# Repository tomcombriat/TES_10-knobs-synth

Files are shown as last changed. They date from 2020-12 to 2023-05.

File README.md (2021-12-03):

# TES - 10 knobs synth
T. Combriat 

10 knobs synths are simple synthesizers based on [Mozzi](https://github.com/sensorium/Mozzi) using STM32 blue pill with 10 knobs. Different versions are available:

  - 10knobs_mono_24bits_MCP4822 is a mono synth built around the MCP4822 dual DAC, with theoritical 24 bits resolution (in practice, around 14/16 bits get outside the noise, but that is already quite a lot). It can easily be turned into a stereo synth with 12bits on each channel.
  - 10knobs_mono_16bits_PT8211 is a mono synth built around the PT8211 dual DAC, with theoritical 16 bits resolution. This one can easily be upgraded to a stereo version: only one channel of the PT8211 is used here.

The aim of this serie is to provide a quite fixed hardware which can be used for different synthesis methods.

***

### Hardware
These synthesizers have: 
* MIDI input and thru
* 10 knobs for controlling parameters (thus the name), note that one is hardwired for logarithmic volume control
* 6.35mm analog (DAC) audio output (mono/stereo)
* standalone power from ~~3~~ 4 AA batteries. This ensures cleaner sound thanks to very stable power lines. This has been changed from 3 to 4 in order to get some room over the signal level for the op-amps.

PCBs for the chip are single faced and can be easily made if one is able to make 220 microns wide tracks. The masks are provided in the hardware folders for each version.

***

### Programming
These synths can be programmed like any other STM32 pills using USB to serial converter. Native USB will usually not work. You will  also need a rather new version of the Arduino IDE with Mozzi installed and modify Mozzi in accordance with the beginning of the sketch or use the [TES forked version of Mozzi](https://github.com/tomcombriat/Mozzi/tree/TES-stable).

As a general matter, the programs tries to use the most of the chip, so it usually needs to be compiled with -O2 or -O3 with the maximum overclock. As the chip is not confined, the OC does not pose any problem.

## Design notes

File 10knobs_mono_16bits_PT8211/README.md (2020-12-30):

## 10 knobs mono

Actual working version of 10 knobs synth. Features an STM32 BluePill, with DAC used defined output (STANDARD_PLUS 24bits of Mozzi @ 32k)

  - hardware folder contains the kicad project and the masks for an homemade PCB (in svg format).
  - softwares folder contains the different Arduino sketches that can be uploaded on this synth.

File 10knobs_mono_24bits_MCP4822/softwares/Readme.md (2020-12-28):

  - Hardware_check: a test sketch for the PCB integrity
  - MCP4922_mono_24bits_SPI2_trimming: a sketch to trim the synth with an oscilloscope (should give a straight line)
  - XORAND_sax_mk2: a remake of the XORAND_sax synth (from the 8k serie): a synth to be used with an EWI. This is a good base if you want to start your own synth.

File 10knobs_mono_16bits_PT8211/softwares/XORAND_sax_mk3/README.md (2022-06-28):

## TES - XORAND sax mk3
T. Combriat

A version of [XORAND synth](https://github.com/tomcombriat/8_knobs_synth/tree/master/XORAND_poly) to be used with an EWI or the [TESaxophone](https://t-e-s.frama.site/en/tesaxophone).
Differences include:
* Polyphony: 16
* Chords on separate MIDI channel
* Breath controlled volume and filter

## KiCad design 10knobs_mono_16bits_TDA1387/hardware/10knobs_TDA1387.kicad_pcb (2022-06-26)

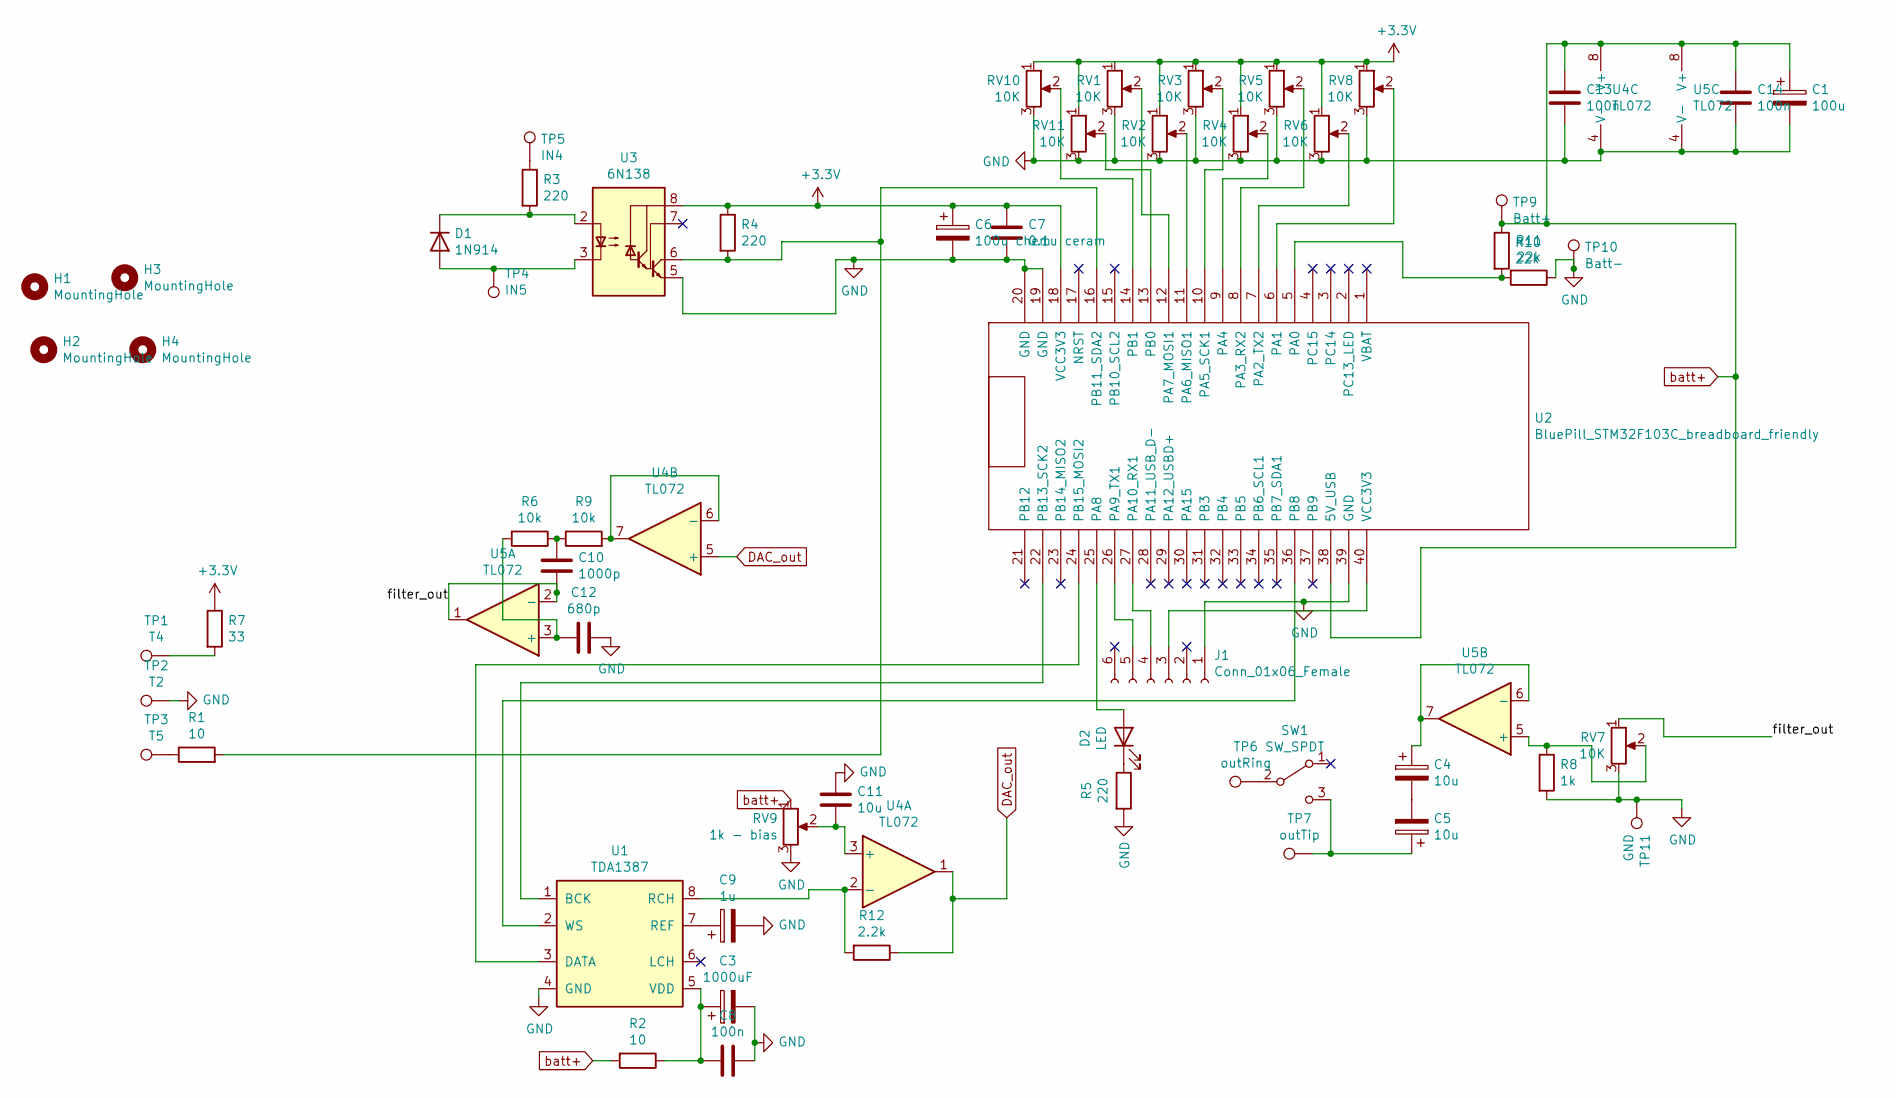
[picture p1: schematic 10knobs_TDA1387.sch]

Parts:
C1: 100u; CP_Radial_D5.0mm_P2.50mm
C3: 1000uF; CP_Radial_D7.5mm_P2.50mm
C4, C5, C11: 10u; CP_Radial_D5.0mm_P2.50mm
C6: 100u chem; CP_Radial_D5.0mm_P2.50mm
C7: 0.1u ceram; C_Disc_D3.0mm_W2.0mm_P2.50mm
C8: 100n; C_Disc_D3.0mm_W2.0mm_P2.50mm
C9: 1u; CP_Radial_D5.0mm_P2.50mm
C10: 1000p; C_Disc_D5.0mm_W2.5mm_P2.50mm
C12: 680p; C_Disc_D5.0mm_W2.5mm_P2.50mm
C13, C14: 100n; C_Disc_D5.0mm_W2.5mm_P2.50mm
D1: 1N914; D_DO-35_SOD27_P7.62mm_Horizontal
D2: LED; LED_D3.0mm
H1, H2, H3, H4: MountingHole; MountingHole_3.2mm_M3_ISO7380_Pad
J1: Conn_01x06_Female; PinHeader_1x06_P2.54mm_Vertical
R1, R2: 10; R_Axial_DIN0207_L6.3mm_D2.5mm_P7.62mm_Horizontal
R3, R4, R5: 220; R_Axial_DIN0207_L6.3mm_D2.5mm_P7.62mm_Horizontal
R6, R9: 10k; R_Axial_DIN0207_L6.3mm_D2.5mm_P7.62mm_Horizontal
R7: 33; R_Axial_DIN0207_L6.3mm_D2.5mm_P7.62mm_Horizontal
R8: 1k; R_Axial_DIN0207_L6.3mm_D2.5mm_P7.62mm_Horizontal
R10, R11: 22k; R_Axial_DIN0207_L6.3mm_D2.5mm_P7.62mm_Horizontal
R12: 2.2k; R_Axial_DIN0207_L6.3mm_D2.5mm_P7.62mm_Horizontal
RV1, RV2, RV3, RV4, RV5, RV6, RV7, RV8, RV10, RV11: 10K; Potentiometer_Alps_RK09K_Single_Vertical
RV9: 1k - bias; Potentiometer_Bourns_3296W_Vertical
SW1: SW_SPDT; PinSocket_1x03_P2.54mm_Vertical
TP1: T4; TestPoint_THTPad_2.5x2.5mm_Drill1.2mm
TP2: T2; TestPoint_THTPad_2.5x2.5mm_Drill1.2mm
TP3: T5; TestPoint_THTPad_2.5x2.5mm_Drill1.2mm
TP4: IN5; TestPoint_THTPad_2.5x2.5mm_Drill1.2mm
TP5: IN4; TestPoint_THTPad_2.5x2.5mm_Drill1.2mm
TP6: outRing; TestPoint_THTPad_2.5x2.5mm_Drill1.2mm
TP7: outTip; TestPoint_THTPad_2.5x2.5mm_Drill1.2mm
TP9: Batt+; TestPoint_THTPad_2.5x2.5mm_Drill1.2mm
TP10: Batt-; TestPoint_THTPad_2.5x2.5mm_Drill1.2mm
TP11: GND; TestPoint_THTPad_2.5x2.5mm_Drill1.2mm
U1: TDA1387; SO-8_3.9x4.9mm_P1.27mm
U2: BluePill_STM32F103C_breadboard_friendly
U3: 6N138; DIP-8_W7.62mm
U4, U5: TL072; DIP-8_W7.62mm_Socket_LongPads

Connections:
+3V3: C6.1, C7.1, R4.1, R7.1, RV1.1, RV2.1, RV3.1, RV4.1, RV5.1, RV6.1, RV8.1, RV10.1, RV11.1, U2.18 (VCC3V3), U3.8 (VCC)
/filter_out: C10.2, RV7.1, U5.1, U5.2 (-)
DAC_out: R12.1, U4.1, U4.5 (+)
GND: C1.2, C3.2, C6.2, C7.2, C8.1, C9.2, C11.1, C12.1, C13.2, C14.2, J1.1, R5.2, R8.2, R11.1, RV1.3, RV2.3, RV3.3, RV4.3, RV5.3, RV6.3, RV7.3, RV8.3, RV9.3, RV10.3, RV11.3, TP2.1, TP10.1, TP11.1, U1.4 (GND), U2.19 (GND), U2.20 (GND), U2.39 (GND), U3.5 (GND), U4.4 (V-), U5.4 (V-)
unnamed: C3.1, C8.2, R2.1, U1.5 (VDD)
unnamed: C4.1, U5.6 (-), U5.7
unnamed: C4.2, C5.2
unnamed: C5.1, SW1.3 (C), TP7.1
unnamed: C9.1, U1.7 (REF)
unnamed: C10.1, R6.1, R9.1
unnamed: C11.2, RV9.2, U4.3 (+)
unnamed: C12.2, R6.2, U5.3 (+)
unnamed: D1.1 (K), R3.2, U3.2 (C1)
unnamed: D1.2 (A), TP4.1, U3.3 (C2)
unnamed: D2.1 (K), R5.1
unnamed: D2.2 (A), U2.25 (PA8)
unnamed: J1.3, U2.40 (VCC3V3)
unnamed: J1.4, U2.27 (PA10_RX1)
unnamed: J1.5, U2.26 (PA9_TX1)
unnamed: R1.1, TP3.1
unnamed: R1.2, R4.2, U2.16 (PB11_SDA2), U3.6 (VO2)
unnamed: R3.1, TP5.1
unnamed: R7.2, TP1.1
unnamed: R8.1, RV7.2, U5.5 (+)
unnamed: R9.2, U4.6 (-), U4.7
unnamed: R10.2, R11.2, U2.5 (PA0)
unnamed: R12.2, U1.8 (RCH), U4.2 (-)
unnamed: RV1.2, U2.12 (PA7_MOSI1)
unnamed: RV2.2, U2.11 (PA6_MISO1)
unnamed: RV3.2, U2.10 (PA5_SCK1)
unnamed: RV4.2, U2.9 (PA4)
unnamed: RV5.2, U2.8 (PA3_RX2)
unnamed: RV6.2, U2.7 (PA2_TX2)
unnamed: RV8.2, U2.6 (PA1)
unnamed: RV10.2, U2.14 (PB1)
unnamed: RV11.2, U2.13 (PB0)
unnamed: SW1.2 (B), TP6.1
unnamed: U1.1 (BCK), U2.22 (PB13_SCK2)
unnamed: U1.2 (WS), U2.36 (PB8)
unnamed: U1.3 (DATA), U2.24 (PB15_MOSI2)
batt+: C1.1, C13.1, C14.1, R2.2, R10.1, RV9.1, TP9.1, U2.38 (5V_USB), U4.8 (V+), U5.8 (V+)

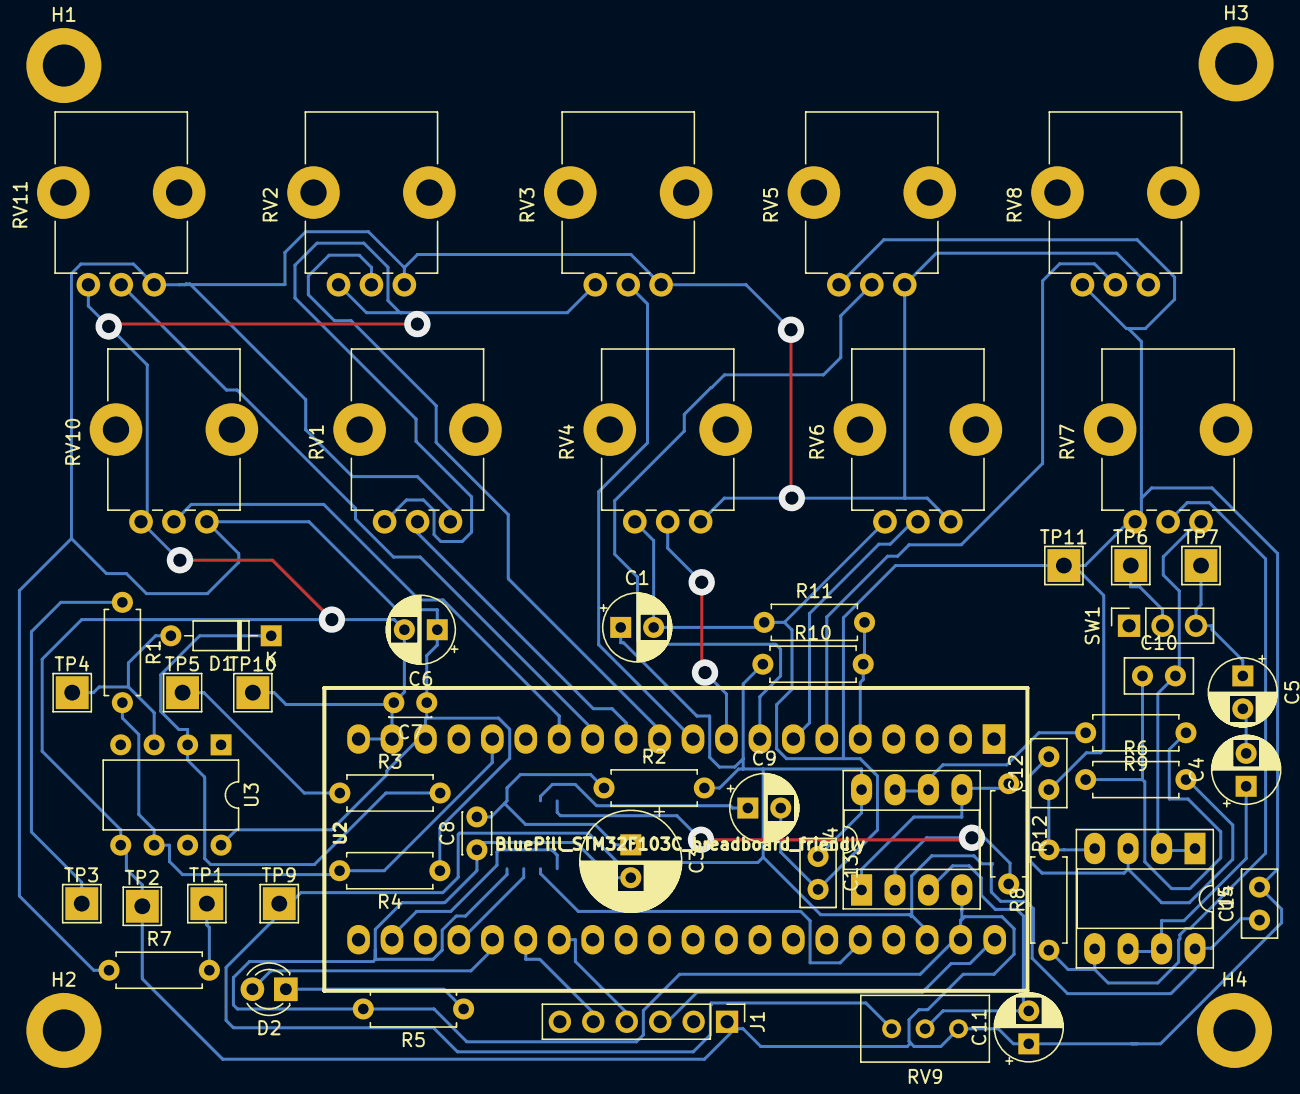
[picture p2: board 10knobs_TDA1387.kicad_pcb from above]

Board: 2 copper layers, 59 parts (1 on the bottom side), 41 nets.

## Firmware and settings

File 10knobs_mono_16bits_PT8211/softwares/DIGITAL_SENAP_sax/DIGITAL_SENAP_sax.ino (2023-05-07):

/*
   Combriat 2022-2023

  Digital Senap Sax mk1
  A 10k synth flavor to be used with an EWI. Supports polyphony (for chords) and breath control over volume or/and filter.



  Mozzi config should be set to use an external audio
  Compilation should be -O3, OC @ 128MHz.

  TODO: battery check.
*/


#define RINGING_CHORDS // chords do not follow breath when in the decaying phase if the breath is higher than their noteOff velocity
#define DITHERING  // dithering before shifting down to 16 bits
#define LEGACYSTM  // this code is normally compiled with the "original" STM32duino. Uncomment this line to use the ST supported core.
#include <MIDI.h>
#include <MozziGuts.h>
#include <Oscil.h>
#include <MetaOscil.h>
#include <SPI.h>

#include <mozzi_rand.h>
#include <mozzi_midi.h>
#include <mozzi_fixmath.h>
#include <Smooth.h>
#include <ADSR.h>
#include <ResonantFilter.h>
#include <AudioDelayFeedback.h>
#include <Portamento.h>
#include "midi_handles.h"
#include "oscil_declaration.h"
#include "dual_type_pot.h"
#include "computeMaxDeviation.h"
#include <tables/cos2048_int8.h>


//#define CONTROL_RATE 4096  // Hz, powers of 2 are most reliable
#define CONTROL_RATE 2048


#define LED PA8

//#define POLYPHONY 12
#define POLYPHONY 10


Oscil<COS2048_NUM_CELLS, AUDIO_RATE> aCarrier[POLYPHONY] = { Oscil<COS2048_NUM_CELLS, AUDIO_RATE>(COS2048_DATA), Oscil<COS2048_NUM_CELLS, AUDIO_RATE>(COS2048_DATA),
                                                             Oscil<COS2048_NUM_CELLS, AUDIO_RATE>(COS2048_DATA), Oscil<COS2048_NUM_CELLS, AUDIO_RATE>(COS2048_DATA),
                                                             Oscil<COS2048_NUM_CELLS, AUDIO_RATE>(COS2048_DATA), Oscil<COS2048_NUM_CELLS, AUDIO_RATE>(COS2048_DATA),
                                                             Oscil<COS2048_NUM_CELLS, AUDIO_RATE>(COS2048_DATA), Oscil<COS2048_NUM_CELLS, AUDIO_RATE>(COS2048_DATA),
                                                             Oscil<COS2048_NUM_CELLS, AUDIO_RATE>(COS2048_DATA), Oscil<COS2048_NUM_CELLS, AUDIO_RATE>(COS2048_DATA) };

Oscil<COS2048_NUM_CELLS, AUDIO_RATE> aMod[POLYPHONY] = { Oscil<COS2048_NUM_CELLS, AUDIO_RATE>(COS2048_DATA), Oscil<COS2048_NUM_CELLS, AUDIO_RATE>(COS2048_DATA),
                                                         Oscil<COS2048_NUM_CELLS, AUDIO_RATE>(COS2048_DATA), Oscil<COS2048_NUM_CELLS, AUDIO_RATE>(COS2048_DATA),
                                                         Oscil<COS2048_NUM_CELLS, AUDIO_RATE>(COS2048_DATA), Oscil<COS2048_NUM_CELLS, AUDIO_RATE>(COS2048_DATA),
                                                         Oscil<COS2048_NUM_CELLS, AUDIO_RATE>(COS2048_DATA), Oscil<COS2048_NUM_CELLS, AUDIO_RATE>(COS2048_DATA),
                                                         Oscil<COS2048_NUM_CELLS, AUDIO_RATE>(COS2048_DATA), Oscil<COS2048_NUM_CELLS, AUDIO_RATE>(COS2048_DATA) };


ADSR<AUDIO_RATE, AUDIO_RATE, unsigned long> envelope[POLYPHONY];

LowPassFilter16 lpf;
Smooth<unsigned int> cutoff_smooth(0.995f);  // 0.999 -> 15ms  // a bit sluggish?// 0.995 -> 7ms
Smooth<unsigned int> rm_smooth(0.995f);      // 0.999 -> 15ms  // a bit sluggish?// 0.995 -> 7ms
Smooth<int> breath_smooth(0.98f);            // if updated at AUDIO_RATE:
// 0.99 -> 15ms maximal raise time
// 0.98 -> 8ms
// 0.9999 -> 1.3s (!!!!)

Smooth<Q16n16> deviation_smooth[POLYPHONY] = { Smooth<Q16n16>(0.001f) };

byte notes[POLYPHONY] = { 100 };

int pitchbend = 0, pitchbend_amp = 2, resonance = 0, breath_sens = 0, volume = 0, breath_on_cutoff = 0, breath_on_rm = 0, prev_resonance = 0, toggle = 0;
byte oscil_state[POLYPHONY], oscil_rank[POLYPHONY], runner = 0, prev_MSB_volume = 0;
bool sustain = false;
bool osc_is_on[POLYPHONY] = { false };
int breath_at_note_off[POLYPHONY] = { 0 }, breath_next = 0;
unsigned int chord_attack = 1, chord_release = 1, cutoff = 0, prev_cutoff = 0, midi_cutoff = 0;
uint32_t deviation_rm;
byte breath_on_vol_LUT[256] = {};

#define COMP_BITS 7
#define COMP_LUT_LEN ((1<<16) * POLYPHONY*(1<<7) >> (16+7-COMP_BITS)) - (1<<COMP_BITS)
#define COMP_TAME 1  // 0 is theoritical equal amp if over limit. higher values allow a positive slope (ie amplitudes keeps increasing but less than with no compression)
byte compressor_LUT[COMP_LUT_LEN] = {};




Q16n16 maxDeviation[8][128];

Q16n16 carrier_freq[POLYPHONY];
Q24n8 mod_freq[POLYPHONY];


Q16n16 deviation_pot;
Q16n16 deviation[POLYPHONY], deviation_sm[POLYPHONY];
Q8n8 mod_to_carrier_ratio, mod_to_carrier_ratio_old;


Q16n16 deviation_rm_pot;



// External audio output parameters and DAC declaration
#ifdef LEGACYSTM
SPIClass mySPI(2);
#else
SPIClass mySPI(PB15, PB14, PB13);
#endif
#define WS_pin PB8


#ifndef LEGACYSTM
HardwareSerial Serial3(PB11, PB10);
#endif
MIDI_CREATE_INSTANCE(HardwareSerial, Serial3, MIDI);


void set_freq(byte i, bool reset_phase = false) {
  osc_is_on[i] = true;
  Q16n16 current_note = Q8n0_to_Q16n16(notes[i]) + (pitchbend << 3) * pitchbend_amp;  // maybe put the shift here instead ?
  Q16n16 freq = Q16n16_mtof(current_note);
  freq = freq >> 1;  // For stable FM, next need to be called, leading to twice the freq as a result

  carrier_freq[i] = freq;

  compute_fm_param(i, reset_phase);
}

inline void compute_fm_param(byte i, bool reset_phase) {
  mod_freq[i] = ((carrier_freq[i] >> 8) * mod_to_carrier_ratio) >> 8;

  aCarrier[i].setFreq_Q16n16(carrier_freq[i]);
  aMod[i].setFreq_Q24n8(mod_freq[i]);
  //aMod[i].setPhaseFractional(aCarrier[i].getPhaseFractional());
  if (reset_phase) {
    aCarrier[i].setPhase(0);
    aMod[i].setPhase(0);
  }

  /*
    Serial.print(i);
    Serial.print(" ");
    Serial.print(aCarrier[i].getPhaseFractional());
    Serial.print(" ");
    Serial.println(aMod[i].getPhaseFractional());*/
}











int three_values_knob(int val, int i) {
  switch (i) {
    case 0:
      {
        if (val > 512) {
          return 0;
        } else return (512 - val);
      }
    case 1:
      {
        if (val < 512) return val;
        else return 1024 - val;
      }
    case 2:
      {
        if (val < 512) return 0;
        else return val - 512;
      }
  }
}




void setup() {
  //Serial.begin(115200);
  pinMode(LED, OUTPUT);
  mySPI.begin();
  delay(100);
  mySPI.beginTransaction(SPISettings(20000000, MSBFIRST, SPI_MODE0));  //MSB first, according to the DAC spec

  pinMode(WS_pin, OUTPUT);

  pinMode(PB1, INPUT_ANALOG);
  pinMode(PB0, INPUT);
  pinMode(PA1, INPUT);
  pinMode(PA2, INPUT);
  pinMode(PA3, INPUT);
  pinMode(PA4, INPUT);
  pinMode(PA5, INPUT);
  pinMode(PA6, INPUT);
  pinMode(PA7, INPUT);

  for (int i = 0; i < 256; i++) {
    if (i != 0) breath_on_vol_LUT[i] = log((float)i) / log(255.) * 255;
    else breath_on_vol_LUT[i] = 0;    
  }
  for (int i= 0;i<COMP_LUT_LEN;i++) 
  {
    compressor_LUT[i] = (unsigned long) (255 << COMP_BITS)/((i>>COMP_TAME)+(1<<COMP_BITS));    // farire le calcul en flottant pour le tame
    /*Serial.print(compressor_LUT[i]);
    Serial.print(" ");
    Serial.println((unsigned long)  (255 << COMP_BITS)/((i>>COMP_TAME)+(1<<COMP_BITS)));*/
  }

// NON, en fait, LUT[POLYPHONY*127]
// Comme 127 eq. 7 bits:
// LUT[i] = (255<<7)/i
//        frac^   ^profondeur minimale d'action (commence à agir à 127 eq 7bits)
// next: breath_next = breath_next*compressor_LUT[sum_env]>>8

/*
On peut encore gagner 127 valeurs:
LUT[i] <--- LUT[i+127]
donc LUT[i] = (255<<7)/(i+127)
next: breath_next = (breath_next * compressor_LUT[((sum_env*breath_next)>>16) - 127]) >> 8 

Pour une LUT plus grande (longueur M bits *potentielle*) qui agit sur 8bits
LUT[i] = (255<<(M))/i) pour i in [1<<M , breath_max*env_max>>(sizeB + sizeE-M)] sizeB = 16, sizeE = 7 (bits)   Note: ici breath_max = sizeB
ensuite breath_next = breath_next * compressor_LUT[((sum_env*breath_next)>> (sizeB+sizeE-M))] logique !
ou, LUT[i] = (255<<M)/(i+1<<M)
et breath_next =() breath_next * compressor_LUT[((sum_env*breath_next)>> (sizeB+sizeE-M)) -(1<<M)]) >> 8

Ici, 7 doit suffire.

Pour un clavier polyphonique, il faut faire des sommes ie.
LUT[i] = (255<<(M))/i) pour i in [1<<M , vol_max*env_max>>(sizeB + sizeE-M)] sizeB = 16, sizeE = 7 (bits)   Note: ici breath_max = sizeB
ensuite vol[i] = vol[i] * compressor_LUT[(sum(env[i]*vol[i])>> (sizeB+sizeE-M))]

*/

  for (byte i = 0; i < POLYPHONY; i++) {
    envelope[i].setADLevels(128, 128);
    envelope[i].setTimes(1, 1, 6500000, 10);
  }

  computeMaxDeviation(maxDeviation[0], 0.0654, 680., 128);
  computeMaxDeviation(maxDeviation[1], 0.0654, 258., 128);
  computeMaxDeviation(maxDeviation[2], 0.0654, 256., 128);
  computeMaxDeviation(maxDeviation[3], 0.0654, 200., 128);
  computeMaxDeviation(maxDeviation[4], 0.0654, 200., 128);
  computeMaxDeviation(maxDeviation[5], 0.0654, 200., 128);
  computeMaxDeviation(maxDeviation[6], 0.0654, 200., 128);
  computeMaxDeviation(maxDeviation[7], 0.0654, 200., 128);




  MIDI.setHandleNoteOn(HandleNoteOn);
  MIDI.setHandleNoteOff(HandleNoteOff);
  MIDI.setHandleControlChange(HandleControlChange);
  MIDI.setHandlePitchBend(HandlePitchBend);
  //  MIDI.setHandleAfterTouchChannel(HandleAfterTouchChannel);


  MIDI.begin(MIDI_CHANNEL_OMNI);
  MIDI.turnThruOff();  // hardwired
  digitalWrite(LED, HIGH);
  delay(100);
  digitalWrite(LED, LOW);
  delay(100);
  digitalWrite(LED, HIGH);
  delay(100);
  digitalWrite(LED, LOW);
  delay(100);
  digitalWrite(LED, HIGH);
  delay(100);

  startMozzi(CONTROL_RATE);
  digitalWrite(LED, LOW);
}







void loop() {
  audioHook();
}




void audioOutput(const AudioOutput f)  // f is a structure containing both channels
{
  digitalWrite(WS_pin, LOW);  //select Right channel
  mySPI.transfer16(f.l());
  digitalWrite(WS_pin, HIGH);  // select Left channel
}





void updateControl() {
  while (MIDI.read())

  if ((volume) == 0) {
    for (byte i = 0; i < POLYPHONY; i++) {
      envelope[i].noteOff();
      osc_is_on[i] = false;  // so that chord do not fade out during next note afer a short pause
      oscil_state[i] = 0;    // everybody reset
      volume = 0;
    }
  }



  toggle++;

  switch (toggle) {
    case 1:
      //mod_to_carrier_ratio = mozziAnalogRead(PA6) >> 2;  //10bits: 2integers, 8 fractionnal (up to 4)
      mod_to_carrier_ratio = dual_type_pot(mozziAnalogRead(PA6));
      if (mod_to_carrier_ratio != mod_to_carrier_ratio_old) {
        mod_to_carrier_ratio_old = mod_to_carrier_ratio;
        for (byte i = 0; i < POLYPHONY; i++) compute_fm_param(i, false);
      }
      break;
    case 2:
      deviation_pot = mozziAnalogRead(PB0) << 10;
      for (byte i = 0; i < POLYPHONY; i++) {
        if (osc_is_on[i]) deviation[i] = min(maxDeviation[Q8n8_to_Q8n0(mod_to_carrier_ratio)][Q16n16_to_Q16n0(Q8n0_to_Q16n16(notes[i]) + (pitchbend << 3) * pitchbend_amp)], deviation_pot);
      }
      break;
    case 3:
      deviation_rm_pot = mozziAnalogRead(PA5) << 4;
      //for (byte i = 0; i < POLYPHONY; i++)  compute_fm_param(i);
      break;
    case 4:
      breath_on_rm = (mozziAnalogRead(PA3) >> 4);
      break;
    case 5:
      chord_release = mozziAnalogRead(PA7) >> 0;
      break;
    case 6:
      chord_attack = mozziAnalogRead(PB1) >> 0;
      break;
    case 7:
      breath_on_cutoff = (mozziAnalogRead(PA4) >> 4);
      break;
    case 8:
      resonance = mozziAnalogRead(PA2);
      break;
    case 9:
      breath_sens = mozziAnalogRead(PA1) >> 4;
      toggle = 0;
      break;
  }

  //for (byte i = 0; i < POLYPHONY; i++) deviation_sm[i] = deviation_smooth[i].next(deviation[i]);/
  for (byte i = 0; i < POLYPHONY; i++) deviation_sm[i] = deviation[i];
}

AudioOutput_t updateAudio() {
  long sample = 0;
  unsigned int amplitude = 0;
  cutoff = cutoff_smooth.next(((breath_on_cutoff * volume) >> 6) + (midi_cutoff << 9));  // >>8
  if (cutoff > 65535) cutoff = 65535;
  if (cutoff != prev_cutoff || resonance != prev_resonance) {
    lpf.setCutoffFreqAndResonance(cutoff, resonance << 4);
    prev_cutoff = cutoff;
    prev_resonance = resonance;
  }
  //breath_next = breath_smooth.next((volume * breath_sens - ((breath_sens - 255) << 14)) >> 11);  //11bits
  //unsigned int tamp_volume = volume * (287-breath_sens);  //14+5 = 19bits
  unsigned int tamp_volume = (volume * (263 - breath_on_vol_LUT[breath_sens]));
  tamp_volume = tamp_volume >> 1;
  if (tamp_volume > 65535) tamp_volume = 65535;  //16 bits
  breath_next = breath_smooth.next(tamp_volume);
  //deviation_rm = rm_smooth.next(((breath_on_rm * volume)>>6) + deviation_rm_pot);
  deviation_rm = rm_smooth.next(((breath_on_rm * volume) >> 6) + deviation_rm_pot << 2);
  //if (deviation_rm > 524288) deviation_rm = 524288;



// COMPRESSOR AMPLITUDE CALCULATION AND APPLICATION

int env_next[POLYPHONY];
  for (byte i = 0; i < POLYPHONY; i++) {
    envelope[i].update();
    env_next[i]=envelope[i].next();
    amplitude += env_next[i];
  amplitude *= breath_next;
  amplitude = amplitude >> (16+7-COMP_BITS); // hopefully optimized away
  if (amplitude > (1<<COMP_BITS))
  { 
    //Serial.print(breath_next);
    breath_next = (breath_next*compressor_LUT[amplitude-(1<<COMP_BITS)]) >> 8;/*
Serial.print(" ");
Serial.println(breath_next);*/
  }
  }

  for (byte i = 0; i < POLYPHONY; i++) {
    //envelope[i].update();
    //int env_next = envelope[i].next();  // for enveloppe to roll even if it is not playing
    // if (!envelope[i].playing() && osc_is_on[i]) osc_is_on[i] = false;
    if (envelope[i].playing() && osc_is_on[i]) {
      long partial_sample = 0;
      Q15n16 modulation_rm = deviation_rm * aCarrier[i].next() >> 8;
      Q15n16 modulation = deviation_sm[i] * aMod[i].phMod(modulation_rm) >> 8;
      partial_sample = aCarrier[i].phMod(modulation);  // 8bits

#ifdef RINGING_CHORDS
      if (breath_at_note_off[i] != 0 && breath_at_note_off[i] < breath_next) partial_sample *= breath_at_note_off[i];

      else partial_sample *= breath_next;
#endif
      sample += (partial_sample * env_next[i]);  // 15bits
    }
  }
#ifndef RINGING_CHORDS
  sample = (sample * breath_next);  //  //31
#endif
#ifdef DITHERING
  sample += rand(-16384, 16384);  //
#endif
  sample = lpf.next(sample >> 15);  // that's 16bits, overflowing with chords? (actually 17 with chords)



  return MonoOutput::fromNBit(18, sample).clip();  //1bit of headroom
}

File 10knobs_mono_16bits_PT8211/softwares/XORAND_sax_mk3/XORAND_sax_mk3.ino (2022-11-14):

/*
   Combriat 2020

  XORAND Sax mk3
  A 10k synth flavor to be used with an EWI. Supports polyphony (for chords) and breath control over volume or/and filter.


  Use the TES-branch of tomcombriat/Mozzi for MetaOsc.


  Mozzi config should be set to use an external audio
  Compilation should be -O3, OC @ 128MHz.

  TODO: battery check.
*/


#define DITHERING   // dithering before shifting down to 16 bits
#include <MIDI.h>
#include <MozziGuts.h>
#include <Oscil.h>
#include<MetaOscil.h>
#include<SPI.h>

#include <mozzi_rand.h>
#include <mozzi_midi.h>
#include <mozzi_fixmath.h>
#include <Smooth.h>
#include <ADSR.h>
#include <LowPassFilter.h>
#include <AudioDelayFeedback.h>
#include <Portamento.h>
#include "midi_handles.h"
#include "oscil_declaration.h"


#define CONTROL_RATE 2048 // Hz, powers of 2 are most reliable
//#define CONTROL_RATE 4096 // Hz, powers of 2 are most reliable

#define LED PA8


Oscil<COS512_NUM_CELLS, AUDIO_RATE> aSin[POLYPHONY] = Oscil<COS512_NUM_CELLS, AUDIO_RATE> (COS512_DATA);
Oscil<COS2048_NUM_CELLS, AUDIO_RATE> LFO[POLYPHONY] = Oscil<COS2048_NUM_CELLS, AUDIO_RATE> (COS2048_DATA);


ADSR <AUDIO_RATE, AUDIO_RATE, unsigned long> envelope[POLYPHONY];

LowPassFilter16 lpf;
//LowPassFilter lpf;
Smooth <unsigned int> cutoff_smooth(0.995f);  // 0.999 -> 15ms  // a bit sluggish?
// 0.995 -> 7ms
Smooth <int> breath_smooth(0.98f);  // if updated at AUDIO_RATE:
// 0.99 -> 15ms maximal raise time
// 0.98 -> 8ms
// 0.9999 -> 1.3s (!!!!)
//Portamento<CONTROL_RATE> porta;

byte notes[POLYPHONY] = {0};
int wet_dry_mix, modulation[POLYPHONY];
int mix1;
int mix2;
int mix_oscil, pitchbend = 0, pitchbend_amp = 2, aftertouch = 0, breath_on_cutoff = 0, resonance = 0, prev_resonance = 0, breath_sens = 0, volume = 0;
byte oscil_state[POLYPHONY], oscil_rank[POLYPHONY], runner = 0, delay_volume = 0, prev_MSB_volume = 0;
bool sustain = false;
bool mod = true;
bool osc_is_on[POLYPHONY] = {false};
unsigned int chord_attack = 1, chord_release = 1, cutoff = 0, prev_cutoff = 0, midi_cutoff = 0;
int toggle = 0;
Q15n16 vibrato;
byte breath_on_vol_LUT[256];





// External audio output parameters and DAC declaration
SPIClass mySPI(2);
#define WS_pin PB8




MIDI_CREATE_INSTANCE(HardwareSerial, Serial3, MIDI);



void set_freq(byte i, bool reset_phase = false)
{

  osc_is_on[i] = true;
  Q16n16 freq = Q16n16_mtof(Q8n0_to_Q16n16(notes[i]) + (pitchbend << 3) * pitchbend_amp);

  aSin[i].setFreq_Q16n16(freq);
  aSquare[i].setFreq_Q16n16(freq);
  aTri[i].setFreq_Q16n16(freq);
  aSaw[i].setFreq_Q16n16(freq);


  if (reset_phase) LFO[i].setPhase(0);
}


int three_values_knob(int val, int i)
{
  switch (i)
  {
    case 0:
      {
        if (val > 512) {
          return 0;
        }
        else return (512 - val);
      }
    case 1:
      {
        if (val < 512) return val;
        else return 1024 - val;
      }
    case 2:
      {
        if (val < 512 ) return 0;
        else return val - 512;
      }
  }
}




void setup() {
  //Serial.begin(115200);
  pinMode(LED, OUTPUT);
  digitalWrite(LED, HIGH);
  mySPI.begin();
  delay(100);
  mySPI.beginTransaction(SPISettings(2000000000, MSBFIRST, SPI_MODE0)); //MSB first, according to the DAC spec

  pinMode(WS_pin, OUTPUT);

  pinMode(PB1, INPUT_ANALOG);
  pinMode(PB0, INPUT);
  pinMode(PA1, INPUT);
  pinMode(PA2, INPUT);
  pinMode(PA3, INPUT);
  pinMode(PA4, INPUT);
  pinMode(PA5, INPUT);
  pinMode(PA6, INPUT);
  pinMode(PA7, INPUT);


  for (int i = 0; i < 256; i++)
  {
    if (i != 0)  breath_on_vol_LUT[i] = log((float) i) / log(255.) * 255;
    else breath_on_vol_LUT[i] = 0;
  }
  for (byte i = 0; i < POLYPHONY; i++)
  {

    envelope[i].setADLevels(128, 128);
    envelope[i].setTimes(1, 1, 6500000, 10);
    aSquare[i].setOscils(&aSq75[i], &aSq81[i], &aSq88[i], &aSq96[i], &aSq106[i], &aSq118[i], &aSq134[i], &aSq154[i], &aSq182[i], &aSq221[i], &aSq282[i], &aSq356[i], &aSq431[i], &aSq546[i], &aSq630[i], &aSq744[i], &aSq910[i], &aSq1170[i], &aSq1638[i], &aSq2730[i], &aSq8192[i]);
    aSquare[i].setCutoffFreqs(75 * 2, 81 * 2, 88 * 2, 96 * 2, 106 * 2, 118 * 2, 134 * 2, 154 * 2, 182 * 2, 221 * 2, 282 * 2, 356 * 2, 431 * 2, 546 * 2, 630 * 2, 744 * 2, 910 * 2, 1170 * 2, 1638 * 2, 2730 * 2, 8192 * 2);

    aSaw[i].setOscils(&aSaw154[i], &aSaw182[i], &aSaw221[i], &aSaw282[i], &aSaw356[i], &aSaw431[i], &aSaw546[i], &aSaw630[i], &aSaw744[i], &aSaw910[i], &aSaw1170[i], &aSaw1638[i], &aSaw2730[i], &aSaw8192[i]);
    aSaw[i].setCutoffFreqs( 154 * 2, 182 * 2, 221 * 2, 282 * 2, 356 * 2, 431 * 2, 546 * 2, 630 * 2, 744 * 2, 910 * 2, 1170 * 2, 1638 * 2, 2730 * 2, 8192 * 2);
    aTri[i].setOscils(&aTri106[i], &aTri118[i], &aTri134[i], &aTri154[i], &aTri182[i], &aTri221[i], &aTri282[i], &aTri356[i], &aTri431[i], &aTri546[i], &aTri630[i], &aTri744[i], &aTri910[i], &aTri1170[i], &aTri1638[i], &aTri2730[i], &aTri8192[i]);
    aTri[i].setCutoffFreqs( 106 * 2, 118 * 2, 134 * 2, 154 * 2, 182 * 2, 221 * 2, 282 * 2, 356 * 2, 431 * 2, 546 * 2, 630 * 2, 744 * 2, 910 * 2, 1170 * 2, 1638 * 2, 2730 * 2, 8192 * 2);
    aSaw[i].setPhase(512 >> 2 );
    aSin[i].setPhase(512 >> 2 );  // test

  }


  lpf.setResonance(25);



  MIDI.setHandleNoteOn(HandleNoteOn);
  MIDI.setHandleNoteOff(HandleNoteOff);
  MIDI.setHandleControlChange(HandleControlChange);
  MIDI.setHandlePitchBend(HandlePitchBend);
  MIDI.setHandleAfterTouchChannel(HandleAfterTouchChannel);

  //Serial.begin(115200);


  MIDI.begin(MIDI_CHANNEL_OMNI);
  delay(100);
  digitalWrite(LED, LOW);
  delay(100);
  digitalWrite(LED, HIGH);
  delay(100);

  MIDI.turnThruOff (); //for speed
  startMozzi(CONTROL_RATE);
  digitalWrite(LED, LOW);

}







void loop() {
  audioHook();
}




void audioOutput(const AudioOutput f) // f is a structure containing both channels
{
  //Serial.println(f.l()>>8);
  // analogWrite(LED, f.l()>>8);
  digitalWrite(WS_pin, LOW);  //select Right channel
  mySPI.transfer16(f.l());


  digitalWrite(WS_pin, HIGH);  // select Left channel
  //  mySPI.transfer16(f.l());
  //digitalWrite(LED, HIGH);
}
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

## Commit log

2020-08-22 Upgraded output on PCB: OA added, Condensators also
    [10knobs.dsn, 10knobs.kicad_pcb, 10knobs.sch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]
2020-08-23 Added PCB, final corrections
    [10knobs.dsn, 10knobs.kicad_pcb, 10knobs.sch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]
2020-08-30 Cleanup, created separated hardware and software folders
    [10knobs.dsn, 10knobs.kicad_pcb, 10knobs.sch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]
2020-08-30 Corrected schematic and PCB
    [10knobs.dsn, 10knobs.kicad_pcb, 10knobs.sch]
2020-09-06 Adapted chords timings, test on filter behavior. Added comments.
2020-09-07 Removed too much digital overdrive
    [XORAND_sax_mk2.ino]
2020-10-08 Corrected wrong behavior with chords
    [XORAND_sax_mk2.ino]
2020-12-10 Version 2.1, with correct MIDI and more stab cap
    [10knobs.dsn, 10knobs.kicad_pcb, 10knobs.sch]
2020-12-11 Changed name
    [10knobs.dsn, 10knobs.kicad_pcb, 10knobs.sch]
2020-12-11 Updated PCB
    [10knobs.kicad_pcb]
2020-12-28 Edited schematic for mono PT8211
    [10knobs_PT8211.kicad_pcb, 10knobs_PT8211.sch]
2020-12-29 Completed mono PT8211 PCB
    [10knobs_PT8211.dsn, 10knobs_PT8211_complete1.kicad_pcb, _saved_10knobs_PT8211.sch]
2020-12-29 Removed auto saves
    [10knobs_PT8211.sch, _saved_10knobs_PT8211.sch]
2020-12-30 Adjusted lpf
    [10knobs_PT8211.kicad_pcb, 10knobs_PT8211.sch]
2021-01-18 Added PCB, removed unneeded files
    [10knobs_PT8211.kicad_pcb]
2021-05-14 Set phase is valid only when an oscillator has been selected, hence not at init
    [XORAND_sax_mk3.ino]
2021-05-23 Adjusted shifts for (hopefully) better precision
    [10knobs_PT8211_complete1.kicad_pcb]
2021-05-24 Added a stab capacitor on the DAC
    [10knobs_PT8211.kicad_pcb, 10knobs_PT8211.sch]
2021-09-20 Correction of HQ midi
    [midi_handles.ino]
2021-12-14 Preliminary work with TDA1387
    [10knobs_TDA1387.dsn, 10knobs_TDA1387.kicad_pcb, 10knobs_TDA1387.sch]
2021-12-27 Finished routing
    [10knobs_TDA1387.dsn, 10knobs_TDA1387.kicad_pcb, 10knobs_TDA1387.sch]
2022-05-07 Improvment of phases
    [10knobs_TDA1387.kicad_pcb]
2022-05-15 Moved things in provision for v2
    [10knobs_PT8211.dsn, 10knobs_PT8211.kicad_pcb, 10knobs_PT8211.sch]
2022-06-26 Moved to seperate folders
    [10knobs_PT8211.kicad_pcb, 10knobs_PT8211.kicad_sch, 10knobs_TDA1387.kicad_pcb]
2022-06-28 Moving it was a mistake
    [XORAND_sax_mk3.ino, midi_handles.ino]
2022-06-28 Prototype of digital senap sax synth
2022-07-10 Enveloppes and filter added
2022-07-23 Corrected same than previous on XORAND
    [midi_handles.ino]
2022-07-23 Corrected chords which were coming back after being shut down
    [DIGITAL_SENAP_sax.ino]
2022-07-24 Fixed PB on digital senap
    [DIGITAL_SENAP_sax.ino]
2022-08-16 Interveted modulation wheel and pot, the pot as more precision hence more interesting for mod_to_carrier_ratio
2022-09-20 Fixed phases problems between notes
    [DIGITAL_SENAP_sax.ino]
2022-11-09 Adapted noteOns to low velocities
2023-04-29 Update to new stm32duino
2023-05-03 Fixed static allocation of oscillators
    [10knobs_PT8211.kicad_sch]
